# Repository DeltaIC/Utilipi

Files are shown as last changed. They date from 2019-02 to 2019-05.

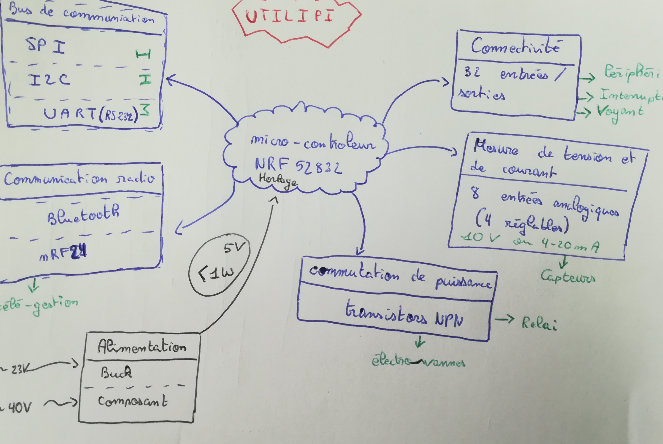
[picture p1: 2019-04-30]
Hardware/schema.jpg

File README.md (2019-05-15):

Overview
---
RPI and NRF for industrial application : 
The board has 2 modes : 
- RPI + NRF : RPI handles all the Features below, and you can add an NRF for extra real time event handling. 
- NRF only : The NRF handles all the features below. You can use it with BLE or RF24. It is compatible with MYSENSORS also. 

Supply voltage up to 24v

**All the features has been tested**

Github : https://github.com/DeltaIC/Utilipi

Openhardware.io : https://www.openhardware.io/view/618/UtiliPi

Features
---

#### IO EXTENDER
There is 32 channels I/O included 16 which can work with interrupt service thank to an I/O expender on I²C bus.

#### ADC
The Analog to Digital Converter have 4 channel 10V max and 4 channel with input selection. The input selection works either for 10V max or 4-20mA loop.

#### SPI, I²C and UART
For each protocol, the connectors are routed to their native port on the raspberry. The level input can be 16V max. For the SPI, 4 channel from the raspberry are used for CS for each connector.

#### Transistors NPN
There is 8 transistors NPN, the collector and emitter pin are available on the connector. For each transistors, a LED show it state (open/close).

#### GPIO
There is 4 channel directly connected to the raspberry. Unlike the others, they are not protected for over-voltage (max 3.3V).

#### POWER
The board can be powered by raspberry (remove the jumper JP1) or it can be powered by external supply (max 36V).
This module also works : https://fr.aliexpress.com/item/mini-DC-DC-Converter-Step-Down-buck-Power-Supply-Module-for-Flight-Control-Car/2038556858.html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

BLOG
---

- **22/08/2018** : Ordering the first board at a PCB manufacturer (JLCPCB)
- **28/08/2018** : The 5 board ordered are arrived, but there is 3 copper areas missing due to editor which don't make good gerber file. Issue post on the user forum. [https://easyeda.com/forum/topic/Copper-area-overlap-bug-deaf372a8630482aa5ac4a56d1aa59e7]
- Testing the board and the routing feature by feature
- **07/09/2018** : I²C adaptateur and IO extender has been soldered, the raspberry succed in discovering slave in the bus. Good point.
- **28/09/2018** : The hole size for connector is too thin, and routage will be update for allowing SPI without using IO extender.
- **30/10/2018** : The transistors, the IOExtender, the I2C and SPI voltage shift works well.
- **31/10/2018** : I've redesign the board according to the mistake i've found. Also, a library from ABElectronic use the IOextender and ease it use. [https://github.com/abelectronicsuk/ABElectronics_Python_Libraries/tree/master/IOPi]
- **25/02/2019** : Add the Github, multiple corrections in the PCB incoming with v2.2
- **28/02/2019** : New version 2.2, add the source code on github
- **29/04/2019** : New version 2.3, add the source code on github. Add the nrf52 to the board.

TO DO
---

- Change the NRF used (to small and need for external antenna connector)
- Change 3V3 supply voltage
- modify solder pad of the io extender (a little small)
- Replace jumper for the ADC 
- correct minor bug (Silkscreen)

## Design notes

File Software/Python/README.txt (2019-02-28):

*****************************I2C****************************

sudo raspi-config
-> activer l'interface i2C

sudo apt-get install i2c-tools
i2cdetect -r -y 1

*****************************github**************************
https://github.com/MomsFriendlyRobotCompany/mcp3208
https://github.com/abelectronicsuk/ABElectronics_Python_Libraries/tree/master/IOPi

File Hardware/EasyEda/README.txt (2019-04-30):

UtiliPi

Github : https://github.com/NathanB49/Utilipi
Openhardware.io : https://www.openhardware.io/view/618/UtiliPi            
How to use：

At editor, Click the document icon on the topbar, via "Document" > "Open" > "EasyEDA Source", and select json file, then open it at the editor.

如何使用：

在编辑器顶部工具栏，点击“文档”图标，选择 “文档” > “打开” > “EasyEDA源码”，选择json文件打开即可。

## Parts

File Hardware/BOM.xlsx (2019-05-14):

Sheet: Proto
REFERENCE | FONCTION | QUANTITE / UTILIPI | PRIX/UNITE | LOT | FOURNISSEUR |  |  | Total | 72.92 €
IMM-NRF52832-NANO |  | 1 | 14.33 € |  | Tindie
FDS6911 | MOSFET canal N | 1 | 1.42 € | 5 | RS
MCP23017 | IO expender | 2 | 1.28 € | 5 | RS
TXB0104D | translateur de tension | 2 | 1.63 € | 5 | RS
LM4040AIM3 | tension de référence | 1 | 1.85 € | 5 | RS
MCP3208 | ADC 12 bit | 1 | 4.68 € | 1 | RS
ACPL-247-500E | Optocoupleur | 2 | 1.74 € | 5 | RS
MMPQ2222A | Transistor NPN | 2 | 1.73 € | 5 | RS
ESQ12037GD | connecteur femelle 2x20 contacts | 1 | 8.35 € | 1 | RS
 | connecteur 2 broches | 1 | 0.78 € | 10 | RS
 | connecteur 4 broches | 5 | 1.35 € | 10 | RS
 | connecteur 6 broches | 4 | 1.77 € | 10 | RS
 | connecteur 10 broches | 7 | 0.71 € | 50 | AliExpress | https://fr.aliexpress.com/item/1756430848.html?productId=1756430848 | https://fr.aliexpress.com/item/32397432750.html?productId=32397432750
PTS810SJK250SMTRLFS | boutton poussoir | 2 | 0.32 € | 20 | RS
KPH-1608QBC-D | LED 0603 Bleu | 1 | 0.12 € | 50 | RS
KP-1608SRC-PRV | LED 0603 Rouge | 1 | 0.07 € | 40 | RS
KP-1608SGC | LED 0603 Vert | 1 | 0.06 € | 40 | RS
MP2307 | Module buck 4.75 V-23 V | 1 | 0.38 € | 2 | AliExpress | https://fr.aliexpress.com/item/mini-DC-DC-Converter-Step-Down-buck-Power-Supply-Module-for-Flight-Control-Car/2038556858.html
MMSZ5226BT1G | Diode zener 3V3 | 1 | 0.19 € | 20 | RS
 | Résistance 27 Ω 0,75W | 1 | 0.34 € | 10 | RS
 | Résistance 100 Ω | 4 | 0.02 € | 50 | RS
 | Résistance 510 Ω | 8 | 0.05 € | 50 | RS
 | Résistance 1k Ω | 18 | 0.04 € | 50 | RS
 | Résistance 10k Ω | 8 | 0.04 € | 50 | RS
 | Résistance 40,2k Ω | 8 | 0.05 € | 50 | RS
 | Condensateur 100 nF | 12 | 0.07 € | 100 | RS
 | Condensateur 10 µF | 1 |  |  | RS
 | PCB | 1 | 5.50 € | 5 | JLCPCB

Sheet: Prod
REFERENCE | FONCTION | QUANTITE / UTILIPI | PRIX/UNITE | LOT | FOURNISSEUR | LIENS |  | Total | 42.98 €
IMM-NRF52832-NANO |  | 1 | 14.33 € |  | Tindie
FDS6911 | MOSFET canal N | 1 | 0.11 € | 10 | AliExpress | https://fr.aliexpress.com/item/Livraison-gratuite-10-pi-ces-FDS6892A-NL-FDS6894AZ-NL-FDS6898A-NL-FDS6911-NL-FDS6975-FDS8333C-FDS8447/32965609018.html
MCP23017 | IO expender | 2 | 0.66 € | 1 | AliExpress | https://fr.aliexpress.com/item/MCP23017-MCP23017-E-SO-MCP23017-E-SS/32789435978.html
TXB0104D | translateur de tension | 2 | 0.81 € | 5 | AliExpress | https://fr.aliexpress.com/item/Free-shippin-5pcs-lot-TXB0104DR-TXB0104D-4-bit-bidirectional-voltage-level-sensing-direction-with-the-car/32698771452.html
LM4040AIM3 | tension de référence | 1 | 0.09 € | 10 | AliExpress | https://fr.aliexpress.com/item/10-pi-ces-LM4040AIM3X-2-5-LM4040AIM3X-LM4040AIM3-LM4040AI-LM4040A-LM4040-SOT23-3-R-f-rence/32878063610.html
MCP3208 | ADC 12 bit | 1 | 1.31 € | 1 | AliExpress | https://fr.aliexpress.com/item/MCP3208-C-I-SL-MCP3208-MCP3208-C-MCP3208-CI-SL/32787536957.html
ACPL-247-500E | Optocoupleur | 2 | 0.34 € | 10 | AliExpress | https://fr.aliexpress.com/item/10-pi-ces-A247-ACPL-247-ACPL-247-500E-SOP-16/32955236841.html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
MMPQ2222A | Transistor NPN | 2 | 0.46 € | 2 | AliExpress | https://fr.aliexpress.com/item/MMPQ6700-MMPQ2222A-MMPQ2907A-MMPQ3904-MMPQ3906-MMPQ3725-2-pcs-lot-SMD/32862885949.html
ESQ12037GD | connecteur femelle 2x20 contacts | 1 | 0.13 € | 10 | AliExpress | https://fr.aliexpress.com/item/10-pi-ces-2X20-broches-Double-rang-e-droite-femelle-broche-en-t-te-2-54/32854215610.html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
 | connecteur 2 broches | 1 | 0.23 € | 20 | AliExpress | https://fr.aliexpress.com/store/product/Small-Batch-10Pcs-lot-Cover-Sides-Vertical-Straight-5-08mm-Pitch-2-Pins-Male-PCB-Electrical/808638_1777994549.html | https://fr.aliexpress.com/item/32397432750.html?productId=32397432750
 | connecteur 4 broches | 5 | 0.41 € | 20 | AliExpress | https://fr.aliexpress.com/store/product/Small-Batch-10Pcs-lot-Cover-Sides-Vertical-Straight-5-08mm-Pitch-2-Pins-Male-PCB-Electrical/808638_1777994549.html | https://fr.aliexpress.com/item/32397432750.html?productId=32397432750
 | connecteur 6 broches | 4 | 0.54 € | 20 | AliExpress | https://fr.aliexpress.com/store/product/Small-Batch-10Pcs-lot-Cover-Sides-Vertical-Straight-5-08mm-Pitch-3-Pins-Male-PCB-Electrical/808638_1762663592.html | https://fr.aliexpress.com/item/32397432750.html?productId=32397432750
 | connecteur 10 broches | 7 | 1.16 € | 20 | AliExpress | https://fr.aliexpress.com/item/1756430848.html?productId=1756430848 | https://fr.aliexpress.com/item/32397432750.html?productId=32397432750
PTS810SJK250SMTRLFS | boutton poussoir | 2 | 0.32 € | 20 | RS
KPH-1608QBC-D | LED 0603 Bleu | 1 | 0.12 € | 50 | RS
KP-1608SRC-PRV | LED 0603 Rouge | 1 | 0.07 € | 40 | RS
KP-1608SGC | LED 0603 Vert | 1 | 0.06 € | 40 | RS
MP2307 | Module buck 4.75 V-23 V | 1 | 0.34 € | 2 | AliExpress | https://fr.aliexpress.com/item/mini-DC-DC-Converter-Step-Down-buck-Power-Supply-Module-for-Flight-Control-Car/2038556858.html
MMSZ5226BT1G | Diode zener 3V3 | 1 | 0.19 € | 20 | RS
 | Résistance 27 Ω 0,75W | 1 | 0.34 € | 10 | RS
 | Résistance 100 Ω | 4 | 0.02 € | 50 | RS
 | Résistance 510 Ω | 8 | 0.05 € | 50 | RS
 | Résistance 1k Ω | 18 | 0.04 € | 50 | RS
 | Résistance 10k Ω | 8 | 0.04 € | 50 | RS
 | Résistance 40,2k Ω | 8 | 0.05 € | 50 | RS
 | Condensateur 100 nF | 12 | 0.07 € | 100 | RS
 | Condensateur 10 µF | 1 |  |  | RS
 | PCB | 1 | 5.50 € | 5 | JLCPCB

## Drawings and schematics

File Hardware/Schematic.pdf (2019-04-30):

+3.3V | +5V
+3.3V

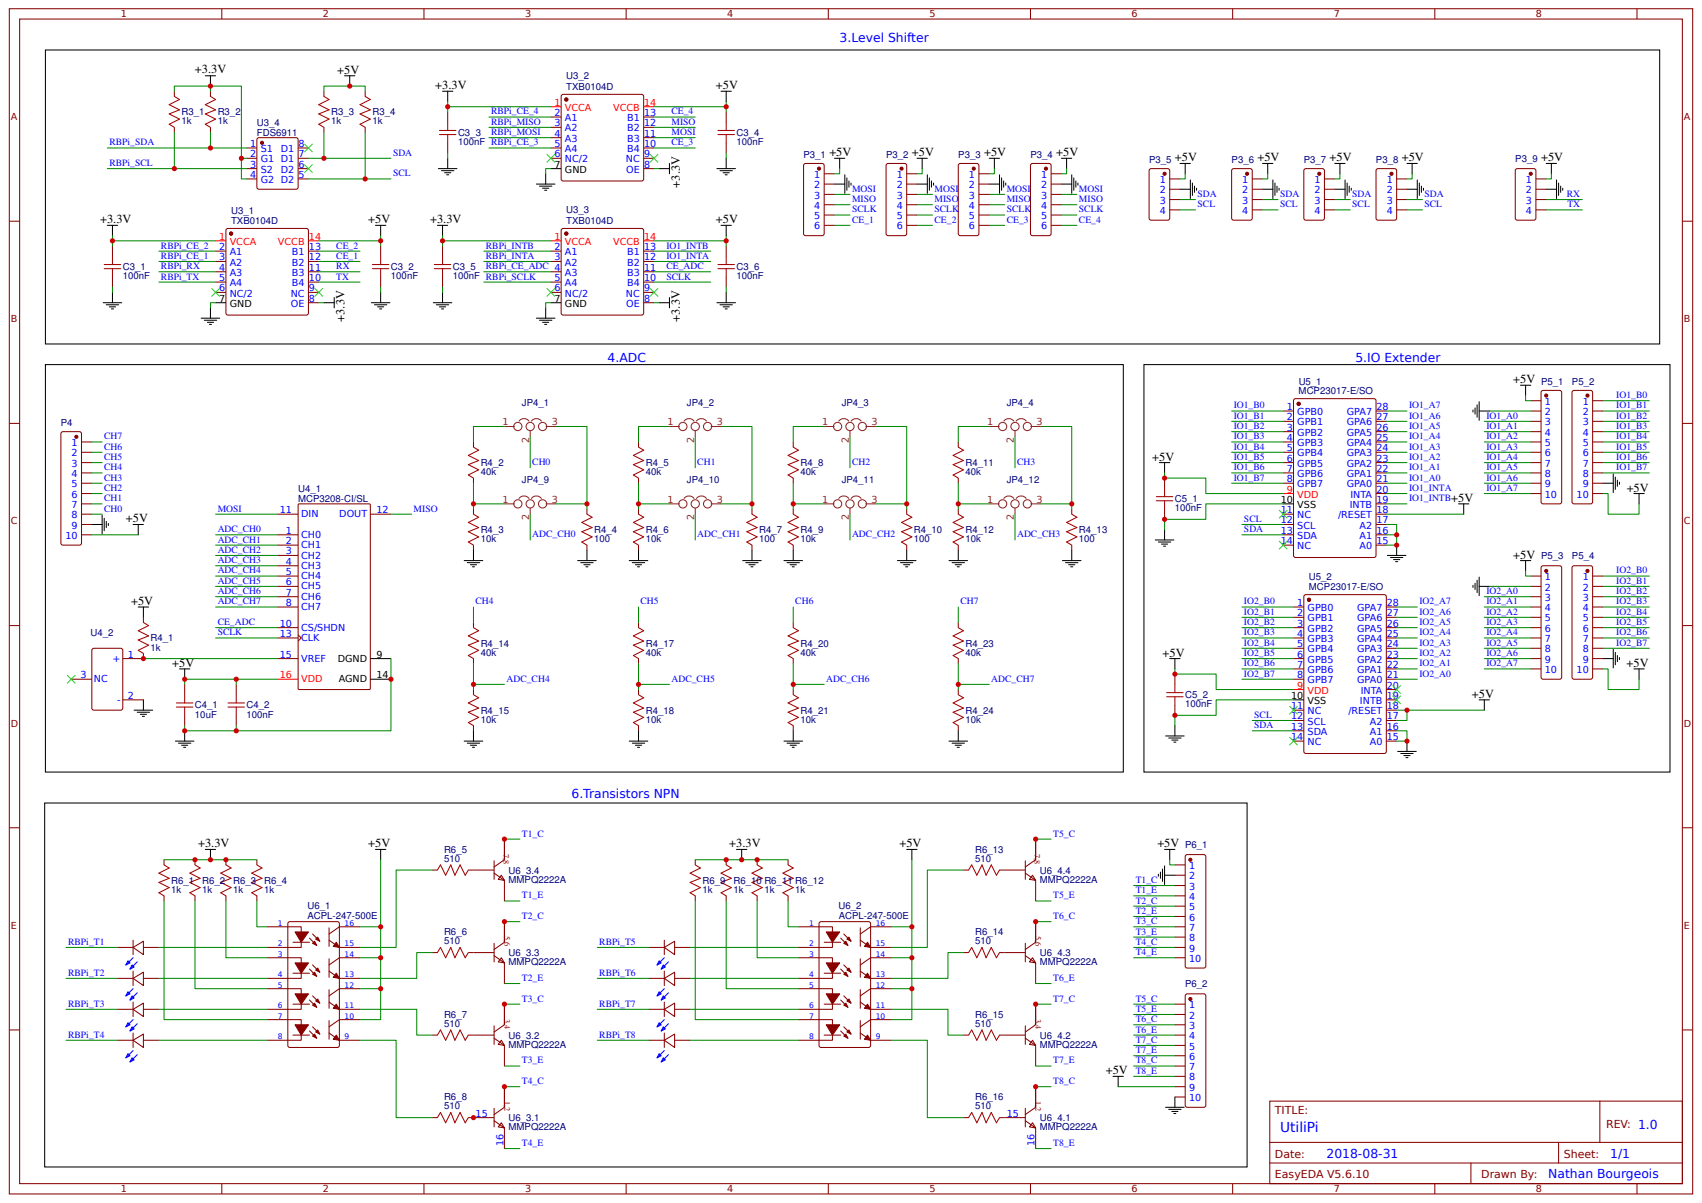
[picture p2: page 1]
TITLE:; UtiliPi; REV: 1.0; Date:; Sheet: 1/1; EasyEDA V5.6.10; Drawn By: Nathan Bourgeois; MCP23017-E/SO; GPB0 1 GPB1 2 GPB2 3 GPB3 4 GPB4 5 GPB5 6 GPB6 7 GPB7 8 VDD 9 VSS 10 NC 11 SCL 12 SDA 13; A0 15 A1 16 A2 17 /RESET 18 INTB 19 INTA 20 GPA0 21 GPA1 22 GPA2 23 GPA3 24 GPA4 25 GPA5 26 GPA6 27 GPA7 28; FDS6911; RBPi_SCL; RBPi_SDA; SDA; SCL; 3.Level Shifter; 4.ADC; 5.IO Extender; 6.Transistors NPN; ADC_CH0; ACPL-247-500E; RBPi_T1; RBPi_T2; RBPi_T3; RBPi_T4; RBPi_T5; RBPi_T6; RBPi_T7; RBPi_T8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

+5V

+5V

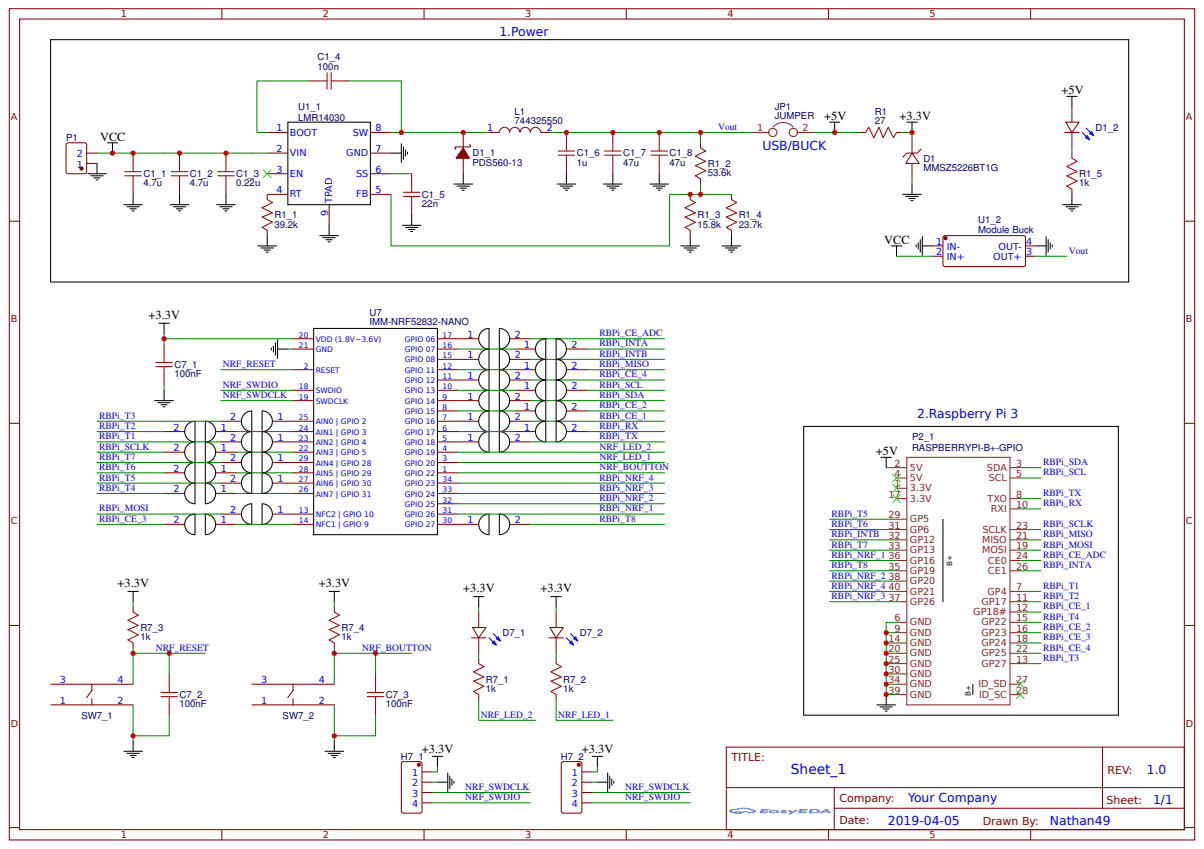
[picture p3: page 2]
TITLE:; Sheet_1; REV: 1.0; Date:; Sheet: 1/1; Drawn By: Nathan49; RASPBERRYPI-B+-GPIO; SDA; SCL; GND 9; MOSI; 19 MISO; 21 SCLK; GND 25; 22 GND 20; GND 14; RXI; 10 TXO; GND 6; GND 30 GND 34; GND 39; RBPi_SDA RBPi_SCL; RBPi_SCLK RBPi_MISO RBPi_MOSI; RBPi_TX RBPi_RX; 2.Raspberry Pi 3; RBPi_CE_ADC; RBPi_T1 RBPi_T2; RBPi_T3; RBPi_T4; RBPi_T5 RBPi_T6; RBPi_T7; RBPi_T8; RBPi_INTB; RBPi_CE_1; RBPi_CE_2 RBPi_CE_3 RBPi_CE_4; RBPi_INTA; 1.Power; JUMPER; USB/BUCK; LMR14030; BOOT 1; VIN 2; GND 7; TPAD 9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

IMM-NRF52832-NANO
GPIO 20 3 GPIO 19 4 GPIO 18 5 GPIO 17 6 GPIO 16 7 GPIO 15 8 GPIO 14 9 GPIO 13 10 GPIO 12 11 GPIO 11 12

GPIO 08 15 GPIO 07 16 GPIO 06 17

AIN3 | GPIO 5 22 AIN2 | GPIO 4 23 AIN1 | GPIO 3 24 AIN0 | GPIO 2 25

AIN7 | GPIO 31 26 AIN6 | GPIO 30 27 AIN5 | GPIO 29 28 AIN4 | GPIO 28 29

GPIO 22 1
GPIO 27 30 GPIO 26 31 GPIO 25 32 GPIO 24 33 GPIO 23 34

Company: Your Company

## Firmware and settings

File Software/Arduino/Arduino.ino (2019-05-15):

// Enable debug prints
#define MY_DEBUG

#define MY_RADIO_NRF5_ESB

//#define MY_RF24_CHANNEL 96

#define MY_RF24_PA_LEVEL RF24_PA_HIGH

#define MY_NODE_ID 11

#include <MySensors.h>
#include <BH1750.h>
#include <Wire.h> 
#include "Adafruit_MCP23017.h"

int RELAY_PIN[] = {PIN_T1,PIN_T2,PIN_T3,PIN_T4,PIN_T5,PIN_T6,PIN_T7,PIN_T8};
#define NUMBER_OF_RELAYS 8 // Total number of attached relays
#define RELAY_ON 0  // GPIO value to write to turn on attached relay
#define RELAY_OFF 1 // GPIO value to write to turn off attached relay
#define CHILD_ID_LIGHT 20
BH1750 lightSensor;
int i;

MyMessage msg(CHILD_ID_LIGHT, V_LIGHT_LEVEL);
// MyMessage msg(CHILD_ID_LIGHT, V_LEVEL);  
uint16_t lastlux;

// Initialize general message
void before()
{
  for (int sensor=1, pin=0; sensor<=NUMBER_OF_RELAYS; sensor++, pin++) {
    // Then set relay pins in output mode
    hwPinMode(RELAY_PIN[pin], OUTPUT_H0H1);
    //pinMode(RELAY_PIN[pin], OUTPUT);
    // Set relay to last known state (using eeprom storage)
    digitalWrite(RELAY_PIN[pin], loadState(sensor)?RELAY_ON:RELAY_OFF);
  }
  pinMode(LED_BUILTIN, OUTPUT);
}

void setup()
{
  Wire.begin();
  lightSensor.begin(BH1750::ONE_TIME_HIGH_RES_MODE);
  
  digitalWrite(LED_BUILTIN,LOW);
}

void presentation()
{
  // Send the sketch version information to the gateway and Controller
  sendSketchInfo("Utilipy", "0.3");

  for (int sensor=1, pin=0; sensor<=NUMBER_OF_RELAYS; sensor++, pin++) {
    // Register all sensors to gw (they will be created as child devices)
    present(sensor, S_BINARY);
  }
  present(CHILD_ID_LIGHT, S_LIGHT_LEVEL);
}

void loop()
{
  uint16_t lux = lightSensor.readLightLevel();// Get Lux value
  if ((lux != lastlux) & (lux != 0)) {
      Serial.println(lux);
      send(msg.set(lux));
      lastlux = lux;
  }

  delay(2000);
}

void receive(const MyMessage &message)
{
  // We only expect one type of message from controller. But we better check anyway.
  if (message.type==V_STATUS) {
    // Change relay state
    digitalWrite(RELAY_PIN[message.sensor-1], message.getBool()?RELAY_ON:RELAY_OFF);
    // Store state in eeprom
    saveState(message.sensor, message.getBool());
    // Write some debug info
    Serial.print("Incoming change for sensor:");
    Serial.print(message.sensor);
    Serial.print(", New status: ");
    Serial.println(message.getBool());
  }
}

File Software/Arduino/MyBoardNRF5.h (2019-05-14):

/*
  If you don't use an nRF5 board, you can ignore this file.

  This file was part of the "My Sensors nRF5 Boards" board repository
  available at https://github.com/mysensors/ArduinoBoards If you have
  questions, please refer the documentation at
  https://github.com/mysensors/ArduinoHwNRF5 first.

  This file is compatible with ArduinoHwNRF5 >= 0.2.0

  This file allows you to change the pins of internal hardware, like the
  serial port, SPI bus or Wire bus.

  All pins referenced here are mapped via the "g_ADigitalPinMap" Array
  defined in "MyBoardNRF5.cpp" to pins of the MCU.
  
  As an example, if you have at the third position in "g_ADigitalPinMap" the
  12, then all ports referenced in Arduino with 2 are mapped to P0.12. If you
  don't change the "g_ADigitalPinMap" Array, the Arduino pins 0..31 are
  translated to P0.00..P0..31.
   
  ###########################################################################
 
  This file is compatible with ArduinoHwNRF5 > 0.1.0
  Copyright (c) 2014-2015 Arduino LLC.  All right reserved.
  Copyright (c) 2016 Sandeep Mistry. All right reserved.
  Copyright (c) 2017 Sensnology AB. All right reserved.

  This library is free software; you can redistribute it and/or
  modify it under the terms of the GNU Lesser General Public
  License as published by the Free Software Foundation; either
  version 2.1 of the License, or (at your option) any later version.
  This library is distributed in the hope that it will be useful,
  but WITHOUT ANY WARRANTY; without even the implied warranty of
  MERCHANTABILITY or FITNESS FOR A PARTICULAR PURPOSE.
  See the GNU Lesser General Public License for more details.
  You should have received a copy of the GNU Lesser General Public
  License along with this library; if not, write to the Free Software
  Foundation, Inc., 51 Franklin St, Fifth Floor, Boston, MA  02110-1301  USA
*/

#ifndef _MYBOARDNRF5_H_
#define _MYBOARDNRF5_H_

#ifdef __cplusplus
extern "C"
{
#endif // __cplusplus


//#define CONFIG_NFCT_PINS_AS_GPIOS

// Number of pins defined in PinDescription array
#define PINS_COUNT           (32u)
#define NUM_DIGITAL_PINS     (32u)
#define NUM_ANALOG_INPUTS    (8u)
#define NUM_ANALOG_OUTPUTS   (8u)

/* 
 *  LEDs
 *  
 *  This is optional
 *  
 *  With My Sensors, you can use
 *  hwPinMode() instead of pinMode()
 *  hwPinMode() allows to use advanced modes like OUTPUT_H0H1 to drive LEDs.
 *  https://github.com/mysensors/MySensors/blob/development/drivers/NRF5/nrf5_wiring_constants.h
 *
 */
#define PIN_LED1                (20)
#define PIN_LED2                (19)
#define LED_BUILTIN          PIN_LED1


/* 
 *  Transistor output
 *  
 *  This is optional
 *  
 *  With My Sensors, you can use
 *  hwPinMode() instead of pinMode()
 *  hwPinMode() allows to use advanced modes like OUTPUT_H0H1 to drive LEDs.
 *  https://github.com/mysensors/MySensors/blob/development/drivers/NRF5/nrf5_wiring_constants.h
 *
 */

#define PIN_T1                (4)
#define PIN_T2                (3)
#define PIN_T3                (2)
#define PIN_T4                (31)
#define PIN_T5                (30)
#define PIN_T6                (29)
#define PIN_T7                (28)
#define PIN_T8                (27)

/* 
 *  To RPI OUTPUT
 *  
 *  This is optional
 *  
 *  With My Sensors, you can use
 *  hwPinMode() instead of pinMode()
 *  hwPinMode() allows to use advanced modes like OUTPUT_H0H1 to drive LEDs.
 *  https://github.com/mysensors/MySensors/blob/development/drivers/NRF5/nrf5_wiring_constants.h
 *
 */

#define PIN_RPI1              (26)
#define PIN_RPI2              (25)
#define PIN_RPI3              (24)
#define PIN_RPI4              (23)
#define PIN_RPI_INT1          (7)
#define PIN_RPI_INT2          (8)

/* 
 *  Buttons
 *  
 *  This is optional
 */
#define PIN_BUTTON1             (22)

/* 
 * Analog ports
 *  
 * If you change g_APinDescription, replace AIN0 with
 * port numbers mapped by the g_APinDescription Array.
 * You can add AIN0 to the g_APinDescription Array if
 * you want provide analog ports MCU independed, you can add
 * AIN0..AIN7 to your custom g_APinDescription Array
 * defined in MyBoardNRF5.cpp
 *
static const uint8_t A0  = ADC_A0;
static const uint8_t A1  = ADC_A1;
static const uint8_t A2  = ADC_A2;
static const uint8_t A3  = ADC_A3;
static const uint8_t A4  = ADC_A4;
static const uint8_t A5  = ADC_A5;
static const uint8_t A6  = ADC_A6;
static const uint8_t A7  = ADC_A7;*/

/*
 * Serial interfaces
 * 
 * RX and TX are required.
 * If you have no serial port, use unused pins
 * CTS and RTS are optional.
 */
#define PIN_SERIAL_RX       (17)
#define PIN_SERIAL_TX       (18)
// #define SERIAL_CTS      (13)
// #define SERIAL_RTS      (14)

/*
 * SPI Interfaces
 * 
 * This is optional
 * 
 * If SPI is defined MISO, MOSI, SCK are required
 * SS is optional and can be used in your sketch.
 */
#define SPI_INTERFACES_COUNT 1
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

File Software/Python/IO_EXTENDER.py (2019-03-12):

#!/usr/bin/env python

"""
================================================
ABElectronics IO Pi | Digital I/O Write Demo

Requires python smbus to be installed
For Python 2 install with: sudo apt-get install python-smbus
For Python 3 install with: sudo apt-get install python3-smbus

run with: python demo_iowrite.py
================================================

This example uses the write_pin and write_port methods to switch the pins
on and off on the I/O bus.

"""
from __future__ import absolute_import, division, print_function, unicode_literals
import time
from MCP23017 import MCP23017


def main():
    '''
    Main program function
    '''

    # Create an instance of the IOPi class with an I2C address of 0x20
    iobus = MCP23017(0x24)

    # We will write to the pins 9 to 16 so set port 1 to be outputs turn off
    # the pins
    iobus.set_port_direction(1, 0x00)
    iobus.write_port(1, 0x00)

    while True:

        time.sleep(0.1)
        iobus.write_pin(16, 1)

        time.sleep(0.1)
        iobus.write_pin(16, 0)

        # repeat until the program ends

if __name__ == "__main__":
    main()

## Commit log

2019-02-25 Comit de la v2
    [Gerber_BoardOutline.GKO, Gerber_BottomLayer.GBL, Gerber_BottomPasteMaskLayer.GBP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]
2019-02-28 Doc + code + PCB/schematic
    [Gerber_BoardOutline.GKO, Gerber_BottomLayer.GBL, Gerber_BottomPasteMaskLayer.GBP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]
2019-03-12 Changement du nom de class "IOPi" en "MCP23017"
2019-03-25 test de push
2019-04-05 Ajout du lien vers le module buck
2019-04-29 Ajout de la version 2.3
    [Gerber_BoardOutline.GKO, Gerber_BottomLayer.GBL, Gerber_BottomPasteMaskLayer.GBP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]
2019-05-14 Réarrangmenet de l'arbo
    [Gerber_BoardOutline.GKO, Gerber_BottomLayer.GBL, Gerber_BottomPasteMaskLayer.GBP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]
2019-05-14 Base fonctionnel MySensors avec relais, capteur BH1750 en I2C, et débug en UART
2019-05-14 suppression des erreurs
    [Gerber_BoardOutline.GKO, Gerber_BottomLayer.GBL, Gerber_BottomPasteMaskLayer.GBP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]
2019-05-14 version 2.1
    [Gerber_BoardOutline.GKO, Gerber_BottomLayer.GBL, Gerber_BottomPasteMaskLayer.GBP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]
2019-05-14 Ajout de la BOM
    [BOM.xlsx]
2019-05-15 modification mineur dans Arduino.ino update of the desciption of the project
